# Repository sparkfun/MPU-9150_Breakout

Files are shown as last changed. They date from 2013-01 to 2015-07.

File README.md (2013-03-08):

9 Degrees of Freedom - MPU-9150 Breakout
========================================

[9 Degrees of Freedom - MPU-9150 Breakout  
*9 Degrees of Freedom - MPU-9150 Breakout (SEN-11486)*](https://www.sparkfun.com/products/11486)

The MPU-9150 is an accelerometer, gyro, and magnetometer all in a single package with an I2C interface. [The datasheet can be found here.](http://dlnmh9ip6v2uc.cloudfront.net/datasheets/Sensors/IMU/PS-MPU-9150A.pdf)

Repository Contents
-------------------

* **/firmware** - An Arduino library with an example that sends raw sensor data out of the serial port
* **/hardware** - All Eagle design files

License Information
-------------------
The hardware is released under [Creative Commons Share-alike 3.0](http://creativecommons.org/licenses/by-sa/3.0/).  
The firmware is released under the [MIT License](http://opensource.org/licenses/MIT).

Hardware author: Aaron Weiss @ SparkFun Electonics  
Firmware original author: [Jeff Rowberg](https://github.com/jrowberg/i2cdevlib) (jeff@rowberg.net); modified by Aaron Weiss (aaron@sparkfun.com)

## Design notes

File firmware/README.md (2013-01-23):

This is example Arduino code that allows you to print raw accelerometer, gyro, and magnetometer data. The original library came from i2cdevlib.com and was based on the very similar MPU-6050, which only used an accelerometer and gyro. The MPU-6050 device library was modified to include raw magnetometer data for the MPU-9150.

To use the library, copy both I2Cdev and MPU6050 into your *libraries* folder in your main Arduino directory. If you don't have a folder called libraries, create one and drop both files in there. Now you can goto the example sketch named *MPU9150_raw* (in MPU6050 -> Examples), open and run the main .ino file.

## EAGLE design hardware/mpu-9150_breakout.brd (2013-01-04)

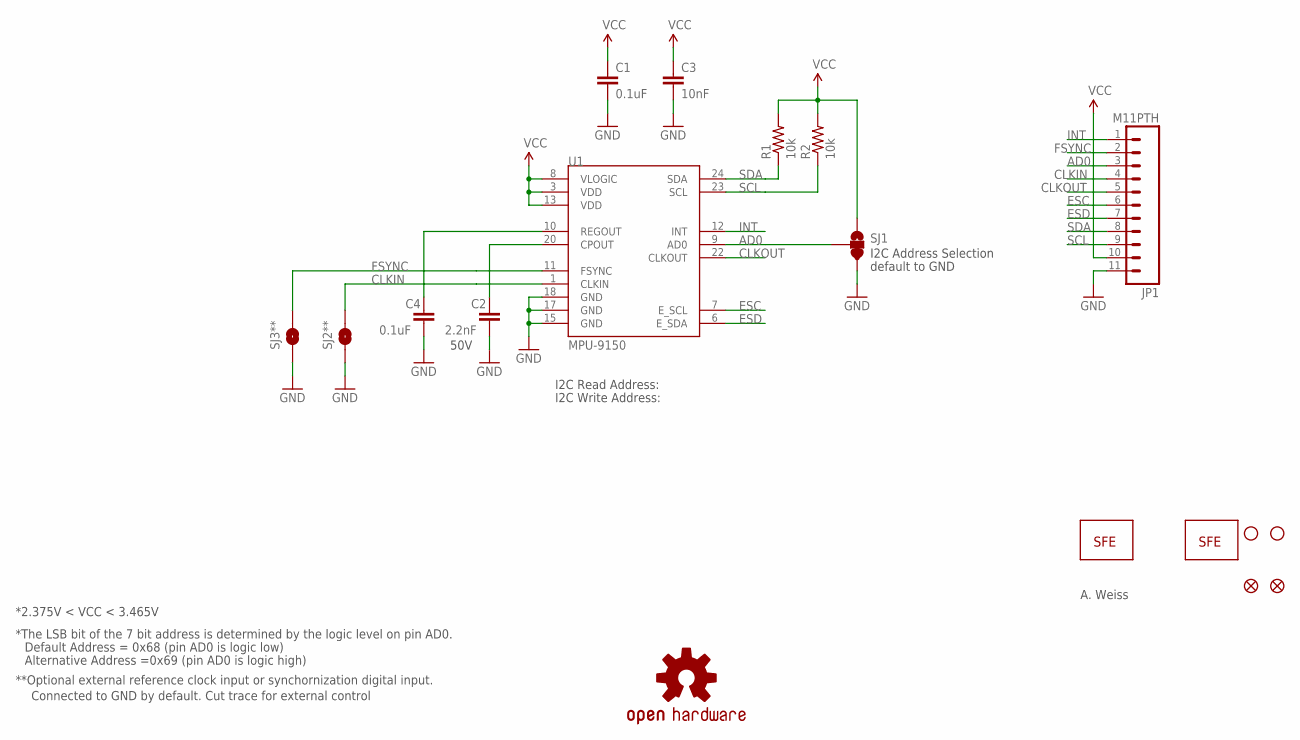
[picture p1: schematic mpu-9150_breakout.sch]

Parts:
C1, C4: 0.1uF; 0402-CAP
C2: 2.2nF; 0402-CAP
C3: 10nF; 0402-CAP
JP1: M11PTH; 1X11
JP2, JP3: STAND-OFF
JP4: LOGO-SFENW2; SFE-NEW-WEB
JP6: LOGO-SFESK; SFE-LOGO-FLAME
JP7, JP8: FIDUCIALUFIDUCIAL; MICRO-FIDUCIAL
R1, R2: 10k; 0402-RES
SJ1: SOLDERJUMPER_2WAYPASTE2&3; SJ_3_PASTE2&3
SJ2**, SJ3**: SOLDERJUMPERTRACE; SJ_2S-TRACE
U1: MPU-9150; QFN-24-NP
U$1: OSHW-LOGOS; OSHW-LOGO-S

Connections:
AD0: JP1.3, SJ1.2, U1.9 (AD0)
CLKIN: JP1.4, SJ2**.2, U1.1 (CLKIN)
CLKOUT: JP1.5, U1.22 (CLKOUT)
ESC: JP1.6, U1.7 (E_SCL)
ESD: JP1.7, U1.6 (E_SDA)
FSYNC: JP1.2, SJ3**.2, U1.11 (FSYNC)
GND: C1.2, C2.2, C3.2, C4.2, JP1.11, SJ1.3, SJ2**.1, SJ3**.1, U1.15 (GND), U1.17 (GND), U1.18 (GND)
INT: JP1.1, U1.12 (INT)
unnamed: C2.1, U1.20 (CPOUT)
unnamed: C4.1, U1.10 (REGOUT)
SCL: JP1.8, R2.1, U1.23 (SCL)
SDA: JP1.9, R1.1, U1.24 (SDA)
VCC: C1.1, C3.1, JP1.10, R1.2, R2.2, SJ1.1, U1.3 (VDD), U1.8 (VLOGIC), U1.13 (VDD)

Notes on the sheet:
50V
I2C Address Selection
**Optional external reference clock input or synchornization digital input.
Connected to GND by default. Cut trace for external control
Default Address = 0x68 (pin AD0 is logic low)
Alternative Address =0x69 (pin AD0 is logic high)
*The LSB bit of the 7 bit address is determined by the logic level on pin AD0.
default to GND
A. Weiss
*2.375V < VCC < 3.465V
I2C Read Address:
I2C Write Address:

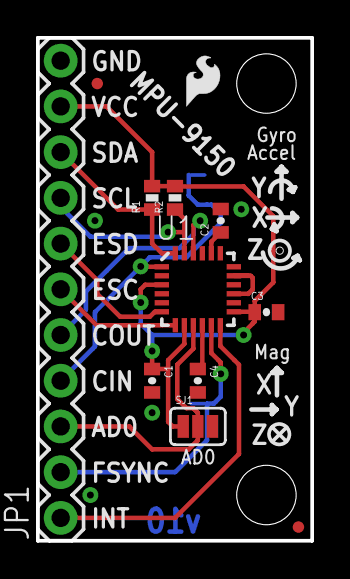
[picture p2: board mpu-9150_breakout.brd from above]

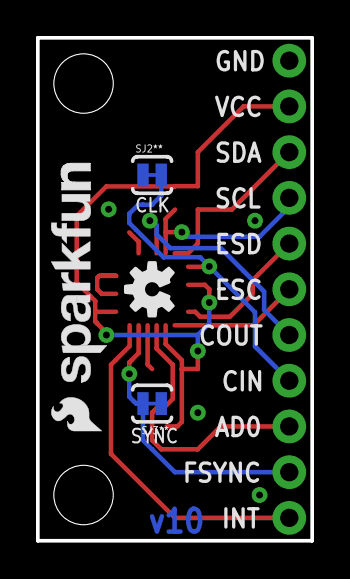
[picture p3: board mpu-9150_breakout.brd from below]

Board: 2 copper layers, 15.2 x 27.9 mm, 19 parts (5 on the bottom side), 13 nets.

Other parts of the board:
JP5: LOGO-SFESK; SFE-LOGO-FLAME

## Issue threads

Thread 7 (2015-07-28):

Serial data randomly stops

canyondellomo, 2015-07-28:
Hi there,

I have a MPU-9150 set up with a Sparkfun 3.3v Pro Micro.  When running this code, serial data transmission will randomly terminate, anywhere from 6 seconds in to over a minute in.  It never lasts for more than around 70 seconds.

How would I fix this issue?  I tried adding a Serial.flush() to hopefully clear up the serial port but it still seems like its getting clogged up.  My only hesitation was that you mentioned it would run on the Pro Micro, so I wanted to ask here for clarification.

Thanks so much,

Canyon

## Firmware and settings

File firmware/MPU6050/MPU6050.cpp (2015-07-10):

// I2Cdev library collection - MPU6050 I2C device class
// Based on InvenSense MPU-6050 register map document rev. 2.0, 5/19/2011 (RM-MPU-6000A-00)
// 8/24/2011 by Jeff Rowberg <jeff@rowberg.net>
// Updates should (hopefully) always be available at https://github.com/jrowberg/i2cdevlib
//
// Changelog:
//     ... - ongoing debug release

// NOTE: THIS IS ONLY A PARIAL RELEASE. THIS DEVICE CLASS IS CURRENTLY UNDERGOING ACTIVE
// DEVELOPMENT AND IS STILL MISSING SOME IMPORTANT FEATURES. PLEASE KEEP THIS IN MIND IF
// YOU DECIDE TO USE THIS PARTICULAR CODE FOR ANYTHING.

/* ============================================
I2Cdev device library code is placed under the MIT license
Copyright (c) 2012 Jeff Rowberg

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
THE SOFTWARE IS PROVIDED "AS IS", WITHOUT WARRANTY OF ANY KIND, EXPRESS OR
IMPLIED, INCLUDING BUT NOT LIMITED TO THE WARRANTIES OF MERCHANTABILITY,
FITNESS FOR A PARTICULAR PURPOSE AND NONINFRINGEMENT. IN NO EVENT SHALL THE
AUTHORS OR COPYRIGHT HOLDERS BE LIABLE FOR ANY CLAIM, DAMAGES OR OTHER
LIABILITY, WHETHER IN AN ACTION OF CONTRACT, TORT OR OTHERWISE, ARISING FROM,
OUT OF OR IN CONNECTION WITH THE SOFTWARE OR THE USE OR OTHER DEALINGS IN
THE SOFTWARE.
===============================================
*/

#include "MPU6050.h"

/** Default constructor, uses default I2C address.
 * @see MPU6050_DEFAULT_ADDRESS
 */
MPU6050::MPU6050() {
    devAddr = MPU6050_DEFAULT_ADDRESS;
}

/** Specific address constructor.
 * @param address I2C address
 * @see MPU6050_DEFAULT_ADDRESS
 * @see MPU6050_ADDRESS_AD0_LOW
 * @see MPU6050_ADDRESS_AD0_HIGH
 */
MPU6050::MPU6050(uint8_t address) {
    devAddr = address;
}

/** Power on and prepare for general usage.
 * This will activate the device and take it out of sleep mode (which must be done
 * after start-up). This function also sets both the accelerometer and the gyroscope
 * to their most sensitive settings, namely +/- 2g and +/- 250 degrees/sec, and sets
 * the clock source to use the X Gyro for reference, which is slightly better than
 * the default internal clock source.
 */
void MPU6050::initialize() {
    setClockSource(MPU6050_CLOCK_PLL_XGYRO);
    setFullScaleGyroRange(MPU6050_GYRO_FS_250);
    setFullScaleAccelRange(MPU6050_ACCEL_FS_2);
    setSleepEnabled(false); // thanks to Jack Elston for pointing this one out!
}

/** Verify the I2C connection.
 * Make sure the device is connected and responds as expected.
 * @return True if connection is valid, false otherwise
 */
bool MPU6050::testConnection() {
    return getDeviceID() == 0x34;
}

// AUX_VDDIO register (InvenSense demo code calls this RA_*G_OFFS_TC)

/** Get the auxiliary I2C supply voltage level.
 * When set to 1, the auxiliary I2C bus high logic level is VDD. When cleared to
 * 0, the auxiliary I2C bus high logic level is VLOGIC. This does not apply to
 * the MPU-6000, which does not have a VLOGIC pin.
 * @return I2C supply voltage level (0=VLOGIC, 1=VDD)
 */
uint8_t MPU6050::getAuxVDDIOLevel() {
    I2Cdev::readBit(devAddr, MPU6050_RA_YG_OFFS_TC, MPU6050_TC_PWR_MODE_BIT, buffer);
    return buffer[0];
}
/** Set the auxiliary I2C supply voltage level.
 * When set to 1, the auxiliary I2C bus high logic level is VDD. When cleared to
 * 0, the auxiliary I2C bus high logic level is VLOGIC. This does not apply to
 * the MPU-6000, which does not have a VLOGIC pin.
 * @param level I2C supply voltage level (0=VLOGIC, 1=VDD)
 */
void MPU6050::setAuxVDDIOLevel(uint8_t level) {
    I2Cdev::writeBit(devAddr, MPU6050_RA_YG_OFFS_TC, MPU6050_TC_PWR_MODE_BIT, level);
}

// SMPLRT_DIV register

/** Get gyroscope output rate divider.
 * The sensor register output, FIFO output, DMP sampling, Motion detection, Zero
 * Motion detection, and Free Fall detection are all based on the Sample Rate.
 * The Sample Rate is generated by dividing the gyroscope output rate by
 * SMPLRT_DIV:
 *
 * Sample Rate = Gyroscope Output Rate / (1 + SMPLRT_DIV)
 *
 * where Gyroscope Output Rate = 8kHz when the DLPF is disabled (DLPF_CFG = 0 or
 * 7), and 1kHz when the DLPF is enabled (see Register 26).
 *
 * Note: The accelerometer output rate is 1kHz. This means that for a Sample
 * Rate greater than 1kHz, the same accelerometer sample may be output to the
 * FIFO, DMP, and sensor registers more than once.
 *
 * For a diagram of the gyroscope and accelerometer signal paths, see Section 8
 * of the MPU-6000/MPU-6050 Product Specification document.
 *
 * @return Current sample rate
 * @see MPU6050_RA_SMPLRT_DIV
 */
uint8_t MPU6050::getRate() {
    I2Cdev::readByte(devAddr, MPU6050_RA_SMPLRT_DIV, buffer);
    return buffer[0];
} 

uint8_t MPU6050::checkMagStatus() {
    I2Cdev::readByte(MPU9150_RA_MAG_ADDRESS, 0x02, buffer);
    return buffer[0];
}


/** Set gyroscope sample rate divider.
 * @param rate New sample rate divider
 * @see getRate()
 * @see MPU6050_RA_SMPLRT_DIV
 */
void MPU6050::setRate(uint8_t rate) {
    I2Cdev::writeByte(devAddr, MPU6050_RA_SMPLRT_DIV, rate);
}

// CONFIG register

/** Get external FSYNC configuration.
 * Configures the external Frame Synchronization (FSYNC) pin sampling. An
 * external signal connected to the FSYNC pin can be sampled by configuring
 * EXT_SYNC_SET. Signal changes to the FSYNC pin are latched so that short
 * strobes may be captured. The latched FSYNC signal will be sampled at the
 * Sampling Rate, as defined in register 25. After sampling, the latch will
 * reset to the current FSYNC signal state.
 *
 * The sampled value will be reported in place of the least significant bit in
 * a sensor data register determined by the value of EXT_SYNC_SET according to
 * the following table.
 *
 * <pre>
 * EXT_SYNC_SET | FSYNC Bit Location
 * -------------+-------------------
 * 0            | Input disabled
 * 1            | TEMP_OUT_L[0]
 * 2            | GYRO_XOUT_L[0]
 * 3            | GYRO_YOUT_L[0]
 * 4            | GYRO_ZOUT_L[0]
 * 5            | ACCEL_XOUT_L[0]
 * 6            | ACCEL_YOUT_L[0]
 * 7            | ACCEL_ZOUT_L[0]
 * </pre>
 *
 * @return FSYNC configuration value
 */
uint8_t MPU6050::getExternalFrameSync() {
    I2Cdev::readBits(devAddr, MPU6050_RA_CONFIG, MPU6050_CFG_EXT_SYNC_SET_BIT, MPU6050_CFG_EXT_SYNC_SET_LENGTH, buffer);
    return buffer[0];
}
/** Set external FSYNC configuration.
 * @see getExternalFrameSync()
 * @see MPU6050_RA_CONFIG
 * @param sync New FSYNC configuration value
 */
void MPU6050::setExternalFrameSync(uint8_t sync) {
    I2Cdev::writeBits(devAddr, MPU6050_RA_CONFIG, MPU6050_CFG_EXT_SYNC_SET_BIT, MPU6050_CFG_EXT_SYNC_SET_LENGTH, sync);
}
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

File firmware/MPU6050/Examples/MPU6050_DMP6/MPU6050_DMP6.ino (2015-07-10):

// I2C device class (I2Cdev) demonstration Arduino sketch for MPU6050 class using DMP (MotionApps v2.0)
// 6/21/2012 by Jeff Rowberg <jeff@rowberg.net>
// Updates should (hopefully) always be available at https://github.com/jrowberg/i2cdevlib
//
// Changelog:
//     2012-06-21 - added note about Arduino 1.0.1 + Leonardo compatibility error
//     2012-06-20 - improved FIFO overflow handling and simplified read process
//     2012-06-19 - completely rearranged DMP initialization code and simplification
//     2012-06-13 - pull gyro and accel data from FIFO packet instead of reading directly
//     2012-06-09 - fix broken FIFO read sequence and change interrupt detection to RISING
//     2012-06-05 - add gravity-compensated initial reference frame acceleration output
//                - add 3D math helper file to DMP6 example sketch
//                - add Euler output and Yaw/Pitch/Roll output formats
//     2012-06-04 - remove accel offset clearing for better results (thanks Sungon Lee)
//     2012-06-01 - fixed gyro sensitivity to be 2000 deg/sec instead of 250
//     2012-05-30 - basic DMP initialization working

/* ============================================
I2Cdev device library code is placed under the MIT license
Copyright (c) 2012 Jeff Rowberg

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
THE SOFTWARE IS PROVIDED "AS IS", WITHOUT WARRANTY OF ANY KIND, EXPRESS OR
IMPLIED, INCLUDING BUT NOT LIMITED TO THE WARRANTIES OF MERCHANTABILITY,
FITNESS FOR A PARTICULAR PURPOSE AND NONINFRINGEMENT. IN NO EVENT SHALL THE
AUTHORS OR COPYRIGHT HOLDERS BE LIABLE FOR ANY CLAIM, DAMAGES OR OTHER
LIABILITY, WHETHER IN AN ACTION OF CONTRACT, TORT OR OTHERWISE, ARISING FROM,
OUT OF OR IN CONNECTION WITH THE SOFTWARE OR THE USE OR OTHER DEALINGS IN
THE SOFTWARE.
===============================================
*/

// Arduino Wire library is required if I2Cdev I2CDEV_ARDUINO_WIRE implementation
// is used in I2Cdev.h
#include "Wire.h"

// I2Cdev and MPU6050 must be installed as libraries, or else the .cpp/.h files
// for both classes must be in the include path of your project
#include "I2Cdev.h"

#include "MPU6050_6Axis_MotionApps20.h"
//#include "MPU6050.h" // not necessary if using MotionApps include file

// class default I2C address is 0x68
// specific I2C addresses may be passed as a parameter here
// AD0 low = 0x68 (default for SparkFun breakout and InvenSense evaluation board)
// AD0 high = 0x69
MPU6050 mpu;

/* =========================================================================
   NOTE: In addition to connection 3.3v, GND, SDA, and SCL, this sketch
   depends on the MPU-6050's INT pin being connected to the Arduino's
   external interrupt #0 pin. On the Arduino Uno and Mega 2560, this is
   digital I/O pin 2.
 * ========================================================================= */

/* =========================================================================
   NOTE: Arduino v1.0.1 with the Leonardo board generates a compile error
   when using Serial.write(buf, len). The Teapot output uses this method.
   The solution requires a modification to the Arduino USBAPI.h file, which
   is fortunately simple, but annoying. This will be fixed in the next IDE
   release. For more info, see these links:

   http://arduino.cc/forum/index.php/topic,109987.0.html
   http://code.google.com/p/arduino/issues/detail?id=958
 * ========================================================================= */



// uncomment "OUTPUT_READABLE_QUATERNION" if you want to see the actual
// quaternion components in a [w, x, y, z] format (not best for parsing
// on a remote host such as Processing or something though)
//#define OUTPUT_READABLE_QUATERNION

// uncomment "OUTPUT_READABLE_EULER" if you want to see Euler angles
// (in degrees) calculated from the quaternions coming from the FIFO.
// Note that Euler angles suffer from gimbal lock (for more info, see
// http://en.wikipedia.org/wiki/Gimbal_lock)
//#define OUTPUT_READABLE_EULER

// uncomment "OUTPUT_READABLE_YAWPITCHROLL" if you want to see the yaw/
// pitch/roll angles (in degrees) calculated from the quaternions coming
// from the FIFO. Note this also requires gravity vector calculations.
// Also note that yaw/pitch/roll angles suffer from gimbal lock (for
// more info, see: http://en.wikipedia.org/wiki/Gimbal_lock)
//#define OUTPUT_READABLE_YAWPITCHROLL

// uncomment "OUTPUT_READABLE_REALACCEL" if you want to see acceleration
// components with gravity removed. This acceleration reference frame is
// not compensated for orientation, so +X is always +X according to the
// sensor, just without the effects of gravity. If you want acceleration
// compensated for orientation, us OUTPUT_READABLE_WORLDACCEL instead.
//#define OUTPUT_READABLE_REALACCEL

// uncomment "OUTPUT_READABLE_WORLDACCEL" if you want to see acceleration
// components with gravity removed and adjusted for the world frame of
// reference (yaw is relative to initial orientation, since no magnetometer
// is present in this case). Could be quite handy in some cases.
//#define OUTPUT_READABLE_WORLDACCEL

// uncomment "OUTPUT_TEAPOT" if you want output that matches the
// format used for the InvenSense teapot demo
#define OUTPUT_TEAPOT



#define LED_PIN 13 // (Arduino is 13, Teensy is 11, Teensy++ is 6)
bool blinkState = false;

// MPU control/status vars
bool dmpReady = false;  // set true if DMP init was successful
uint8_t mpuIntStatus;   // holds actual interrupt status byte from MPU
uint8_t devStatus;      // return status after each device operation (0 = success, !0 = error)
uint16_t packetSize;    // expected DMP packet size (default is 42 bytes)
uint16_t fifoCount;     // count of all bytes currently in FIFO
uint8_t fifoBuffer[64]; // FIFO storage buffer

// orientation/motion vars
Quaternion q;           // [w, x, y, z]         quaternion container
VectorInt16 aa;         // [x, y, z]            accel sensor measurements
VectorInt16 aaReal;     // [x, y, z]            gravity-free accel sensor measurements
VectorInt16 aaWorld;    // [x, y, z]            world-frame accel sensor measurements
VectorFloat gravity;    // [x, y, z]            gravity vector
float euler[3];         // [psi, theta, phi]    Euler angle container
float ypr[3];           // [yaw, pitch, roll]   yaw/pitch/roll container and gravity vector

// packet structure for InvenSense teapot demo
uint8_t teapotPacket[14] = { '$', 0x02, 0,0, 0,0, 0,0, 0,0, 0x00, 0x00, '\r', '\n' };



// ================================================================
// ===               INTERRUPT DETECTION ROUTINE                ===
// ================================================================

volatile bool mpuInterrupt = false;     // indicates whether MPU interrupt pin has gone high
void dmpDataReady() {
    mpuInterrupt = true;
}



// ================================================================
// ===                      INITIAL SETUP                       ===
// ================================================================

void setup() {
    // join I2C bus (I2Cdev library doesn't do this automatically)
    Wire.begin();

    // initialize serial communication
    // (115200 chosen because it is required for Teapot Demo output, but it's
    // really up to you depending on your project)
    Serial.begin(115200);
    while (!Serial); // wait for Leonardo enumeration, others continue immediately

    // NOTE: 8MHz or slower host processors, like the Teensy @ 3.3v or Ardunio
    // Pro Mini running at 3.3v, cannot handle this baud rate reliably due to
    // the baud timing being too misaligned with processor ticks. You must use
    // 38400 or slower in these cases, or use some kind of external separate
    // crystal solution for the UART timer.

    // initialize device
    Serial.println(F("Initializing I2C devices..."));
    mpu.initialize();

    // verify connection
    Serial.println(F("Testing device connections..."));
    Serial.println(mpu.testConnection() ? F("MPU6050 connection successful") : F("MPU6050 connection failed"));

    // wait for ready
    Serial.println(F("\nSend any character to begin DMP programming and demo: "));
    while (Serial.available() && Serial.read()); // empty buffer
    while (!Serial.available());                 // wait for data
    while (Serial.available() && Serial.read()); // empty buffer again

    // load and configure the DMP
    Serial.println(F("Initializing DMP..."));
    devStatus = mpu.dmpInitialize();
    
    // make sure it worked (returns 0 if so)
    if (devStatus == 0) {
        // turn on the DMP, now that it's ready
        Serial.println(F("Enabling DMP..."));
        mpu.setDMPEnabled(true);

        // enable Arduino interrupt detection
        Serial.println(F("Enabling interrupt detection (Arduino external interrupt 0)..."));
        attachInterrupt(0, dmpDataReady, RISING);
        mpuIntStatus = mpu.getIntStatus();

        // set our DMP Ready flag so the main loop() function knows it's okay to use it
        Serial.println(F("DMP ready! Waiting for first interrupt..."));
        dmpReady = true;

        // get expected DMP packet size for later comparison
        packetSize = mpu.dmpGetFIFOPacketSize();
    } else {
        // ERROR!
        // 1 = initial memory load failed
        // 2 = DMP configuration updates failed
        // (if it's going to break, usually the code will be 1)
        Serial.print(F("DMP Initialization failed (code "));
        Serial.print(devStatus);
        Serial.println(F(")"));
    }

    // configure LED for output
    pinMode(LED_PIN, OUTPUT);
}



// ================================================================
// ===                    MAIN PROGRAM LOOP                     ===
// ================================================================

void loop() {
    // if programming failed, don't try to do anything
    if (!dmpReady) return;

    // wait for MPU interrupt or extra packet(s) available
    while (!mpuInterrupt && fifoCount < packetSize) {
        // other program behavior stuff here
        // .
        // .
        // .
        // if you are really paranoid you can frequently test in between other
        // stuff to see if mpuInterrupt is true, and if so, "break;" from the
        // while() loop to immediately process the MPU data
        // .
        // .
        // .
    }

    // reset interrupt flag and get INT_STATUS byte
    mpuInterrupt = false;
    mpuIntStatus = mpu.getIntStatus();

    // get current FIFO count
    fifoCount = mpu.getFIFOCount();

    // check for overflow (this should never happen unless our code is too inefficient)
    if ((mpuIntStatus & 0x10) || fifoCount == 1024) {
        // reset so we can continue cleanly
        mpu.resetFIFO();
        Serial.println(F("FIFO overflow!"));

    // otherwise, check for DMP data ready interrupt (this should happen frequently)
    } else if (mpuIntStatus & 0x01) {
        // wait for correct available data length, should be a VERY short wait
        while (fifoCount < packetSize) fifoCount = mpu.getFIFOCount();

        // read a packet from FIFO
        mpu.getFIFOBytes(fifoBuffer, packetSize);
        
        // track FIFO count here in case there is > 1 packet available
        // (this lets us immediately read more without waiting for an interrupt)
        fifoCount -= packetSize;

        #ifdef OUTPUT_READABLE_QUATERNION
            // display quaternion values in easy matrix form: w x y z
            mpu.dmpGetQuaternion(&q, fifoBuffer);
            Serial.print("quat\t");
            Serial.print(q.w);
            Serial.print("\t");
            Serial.print(q.x);
            Serial.print("\t");
            Serial.print(q.y);
            Serial.print("\t");
            Serial.println(q.z);
        #endif

        #ifdef OUTPUT_READABLE_EULER
            // display Euler angles in degrees
            mpu.dmpGetQuaternion(&q, fifoBuffer);
            mpu.dmpGetEuler(euler, &q);
            Serial.print("euler\t");
            Serial.print(euler[0] * 180/M_PI);
            Serial.print("\t");
            Serial.print(euler[1] * 180/M_PI);
            Serial.print("\t");
            Serial.println(euler[2] * 180/M_PI);
        #endif

        #ifdef OUTPUT_READABLE_YAWPITCHROLL
            // display Euler angles in degrees
            mpu.dmpGetQuaternion(&q, fifoBuffer);
            mpu.dmpGetGravity(&gravity, &q);
            mpu.dmpGetYawPitchRoll(ypr, &q, &gravity);
            Serial.print("ypr\t");
            Serial.print(ypr[0] * 180/M_PI);
            Serial.print("\t");
            Serial.print(ypr[1] * 180/M_PI);
            Serial.print("\t");
            Serial.println(ypr[2] * 180/M_PI);
        #endif

        #ifdef OUTPUT_READABLE_REALACCEL
            // display real acceleration, adjusted to remove gravity
            mpu.dmpGetQuaternion(&q, fifoBuffer);
            mpu.dmpGetAccel(&aa, fifoBuffer);
            mpu.dmpGetGravity(&gravity, &q);
            mpu.dmpGetLinearAccel(&aaReal, &aa, &gravity);
            Serial.print("areal\t");
            Serial.print(aaReal.x);
            Serial.print("\t");
            Serial.print(aaReal.y);
            Serial.print("\t");
            Serial.println(aaReal.z);
        #endif

        #ifdef OUTPUT_READABLE_WORLDACCEL
            // display initial world-frame acceleration, adjusted to remove gravity
            // and rotated based on known orientation from quaternion
            mpu.dmpGetQuaternion(&q, fifoBuffer);
            mpu.dmpGetAccel(&aa, fifoBuffer);
            mpu.dmpGetGravity(&gravity, &q);
            mpu.dmpGetLinearAccelInWorld(&aaWorld, &aaReal, &q);
            Serial.print("aworld\t");
            Serial.print(aaWorld.x);
            Serial.print("\t");
            Serial.print(aaWorld.y);
            Serial.print("\t");
            Serial.println(aaWorld.z);
        #endif
    
        #ifdef OUTPUT_TEAPOT
            // display quaternion values in InvenSense Teapot demo format:
            teapotPacket[2] = fifoBuffer[0];
            teapotPacket[3] = fifoBuffer[1];
            teapotPacket[4] = fifoBuffer[4];
            teapotPacket[5] = fifoBuffer[5];
            teapotPacket[6] = fifoBuffer[8];
            teapotPacket[7] = fifoBuffer[9];
            teapotPacket[8] = fifoBuffer[12];
            teapotPacket[9] = fifoBuffer[13];
            Serial.write(teapotPacket, 14);
            teapotPacket[11]++; // packetCount, loops at 0xFF on purpose
        #endif

        // blink LED to indicate activity
        blinkState = !blinkState;
        digitalWrite(LED_PIN, blinkState);
    }
}

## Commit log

2013-01-04 editied schematic
    removed some old txt
2013-01-23 fixed mag output
    mag output was actually accel output. needed to enable bypass mode on
    the 9150, then enable the mag
    [MPU6050.cpp]
2013-12-20 Fixing SDA/SCL labels on schematic
    [mpu-9150_breakout.sch]
2014-04-10 Create MPU9150_AHRS
    Sketch to read accelerometer, gyro, and magnetometer data from MPU9150 sensor and fuse the sensor input to a quaternion representation using Madgwick's or Mahony's open-source 9 DoF sensor fusion fil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
    Sketch runs on a 3.3 8 MHz Pro Mini Arduino microcontroller with filter update rates of between 125 and 165 Hz.
2014-04-10 Update MPU6050_9Axis_MotionApps41.h
    Added read functions for gyro and magnetometer
2014-04-10 Update MPU6050.h
    Added read function for gyro and magnetometer
2014-04-10 Update MPU6050.cpp
    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
2015-03-07 Changed from using prog_uchar types so the motion apps files compile in Arduino 1.6.0
2015-07-10 Corrected mask on DATA_RDY_INT
    [MPU6050_DMP6.ino]
2016-02-04 Typos?
    The header description had the the file's name wrong, and the note about the maximum voltage referred to another IMU (LSM9DS0).
    [MPU9150_AHRS.ino]

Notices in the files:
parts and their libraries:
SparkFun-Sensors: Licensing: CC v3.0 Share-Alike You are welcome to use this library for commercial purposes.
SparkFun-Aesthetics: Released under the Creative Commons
